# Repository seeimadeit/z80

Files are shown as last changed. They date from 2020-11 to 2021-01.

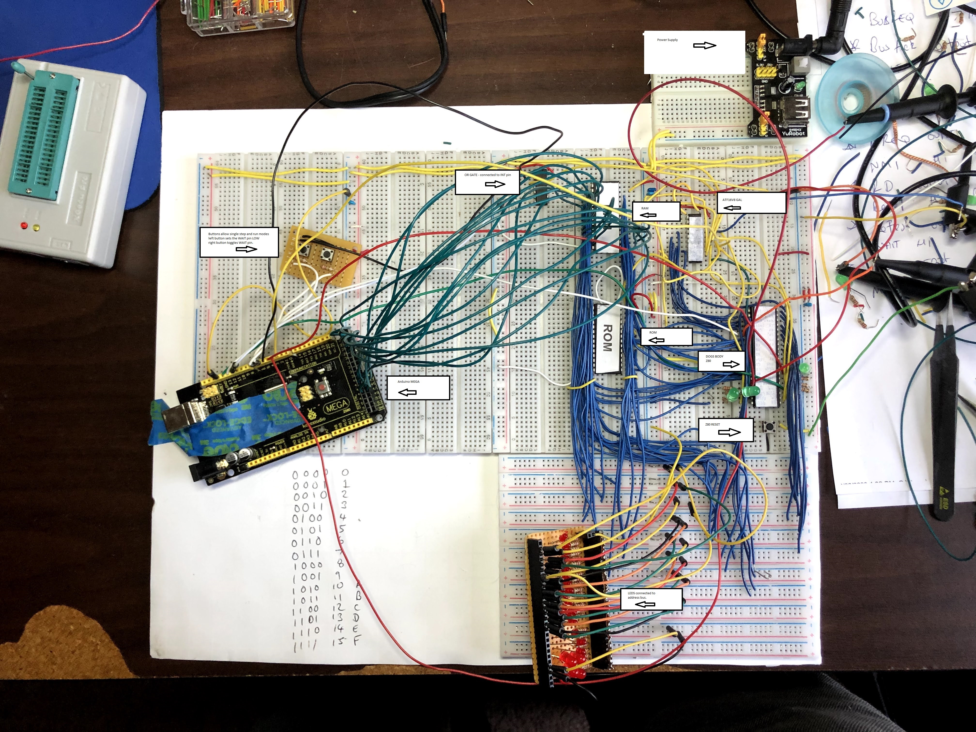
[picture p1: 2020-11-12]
initial/pictures/initialdesign.jpg

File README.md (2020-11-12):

# z80
my z80 based computer

my tools
---- arduino mega ----
during project startup im using it to provide a clock source and a serial port configured as a device on the z80 so I use it for basic keyboard IO.
the project will remove this at some point in the future..
https://www.arduino.cc/en/software

----- chip programmer ---
tl866II plus
www.xgecu.com
rom - at28c64b
gal - ATF16LV8CZ - provides logic for rom and ram selection.
source code for GAL and ROM available on github

------ svn tool ---
oxygenxml

----- gal programming language ----
wincupl

https://www.microchip.com/design-centers/fpgas-and-plds/splds-cplds/pld-design-resources

-------- rom code -----
vasm
http://sun.hasenbraten.de/vasm/
initial rom code written with vasm. I'll be moving to z88dk in the future.

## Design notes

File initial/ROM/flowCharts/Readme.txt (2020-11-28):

free for non-commerial use

ClickCharts Diagram & Flowchart Software
https://www.nchsoftware.com/chart/index.html

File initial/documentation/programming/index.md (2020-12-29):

# Index

[some ideas](ideas.md)

[library](library.md)
[processinfo](processinfo.md)
[commandline](commandline.md)

A

B

C  

[createprocess](createprocess.md)  

D  

filesystem - primitive functions, probably going to change  

[directoryopen](directory.md) 

[directorynextfile](directory.md) 

E

F

G  

[getcommandparams](getcommandparams.md)

[getfilename](directory.md) 

[getmalloctable](getmalloctable.md)

[getprocid](getprocid.md)

[getprocessbyid](getprocessbyid.md)

H  

[hextobyte.md](hextobyte.md) 

I

J

K

L  

[loadfile](loadfile.md)  

M  

[memset](memset.md)  

N

[nextprocessinfo](startprocessinfo.md)

O

P

[print](print.md) 

[println](print.md)

[printhex](printhex.md)  

[printhexL](printhex.md)  

[putc](putc.md) 

[processinfo](processinfo.md)

Q

R

S  
[strcpy](strcpy.md)

[strncpy](strncpy.md)  

[strlen](strlen.md)

[startprocessinfo](startprocessinfo.md)

[setresetpage](setresetpage.md) - memory alloc table management

T  

[touppercase](touppercase.md)

U

V

W

X

Y

Z

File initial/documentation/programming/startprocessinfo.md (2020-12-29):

# startprocessinfo

;#== startprocessinfo ==#  
;# reset the process info list pointer  
;# no inputs, no outputs  

;#== nextprocessinfo ===#  
;# return in hl the next processinfo entry  
;# also updates currentprocessinfo  
;# if carry flag set, we have reach the end of the process table

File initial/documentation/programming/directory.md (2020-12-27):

[index.md](index.md)
# directory utils

**directoryopen** - no inputs , outputs  
    opens the directory  
    
**directorynextfile** - no inpts , no outputs  
    advances to the next file  
    
**getfilename**  
    return the current filename in the HL register pair  
	;# === getfilename of currently open file ===#  
	;# ld hl,storagelocation - for the filename  
	;# call getfilename  

```
.include "Routines.inc"
.include "libs.inc"

	ld hl,dirmsg
	call println
	call directoryopen
currentfile:
	ld hl,thisfilename
	call getfilename
	call println

	ld a,(hl)
	cp 0
	jp z,_exit$1

	call directorynextfile
	jp currentfile

_exit$1:
	ret

thisfilename: .space 15
dirmsg: .string "\r\nDIRECTORY\r\n"

ENDADDRESS:
```

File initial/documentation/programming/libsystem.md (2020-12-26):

[index.md](index.md)
# system library

the system library is normally loaded automatically through Routines.inc and libs.inc

```
.include "Routines.inc"
.include "libs.inc"

```

.equ PRINT,		1  

.equ PRINTLN,	9  

.equ PRINTHEX,	2  

.equ LOADFILE,	3  

.equ MEMSET,	4  

.equ STRLEN,	5  

.equ PUTC,		6  

.equ TOUPPERCASE,7  

.equ HEXTOBYTE,	8  
[hextobyte.md](hextobyte.md)

.equ STRNCPY,10  

.equ CREATEPROCESS,16  

.equ GETCOMMANDPARAMS,17  

filesystem - primitive functions, probably going to change  

.equ DIRECTORYOPEN,13 

.equ DIRECTORYNEXTFILE,14  

.equ GETFILENAME,15

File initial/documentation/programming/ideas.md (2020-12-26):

# Ideas

1. malloc implementation  

            a program will be able list memory allocated
1. copy and paste ability
1. multitasking - can't start until the hardware is fully developed, ie. it needs a timer
1. move keyboard handler into kernel

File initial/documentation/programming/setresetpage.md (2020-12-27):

[index.md](index.md)
# setresetpage

;# ======= setresetpage - memory alloc table management ===#  
setresetpage:  
;# ld a, page  
;# ld b, setorreset , 0 = reset, 1 = set  

```

.include "Routines.inc"
.include "libs.inc"

	ld hl,params
	call getcommandparams
	call touppercase
		call strlen
		ld a,b
	
		cp 3
		jp nz, error

		ld ix,params ;# get the 1st and 2nd characters into the lobyte
		ld a,(ix)
		sub '0'
	
		ld b,a ;# flag 0 = reset, 1 = set
		ld h,(ix+1)
		ld l,(ix+2)
		call hextobyte

		call setresetpage
		ld a,0
		ret
error:
	ld hl,errormsg
	call println
	ld a,0
	ret

  errormsg: .string "syntax: setmat aXX where a = set or reset (1 or 0), XX page (see m*)"
  
	params: .space 50
ENDADDRESS:
```

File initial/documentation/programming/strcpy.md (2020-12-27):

[index.md](index.md)
# strcpy

# === strcpy == #  
	;# copy from source into destination string is zero terminated, no validation is done  
	;# ld hl,source  
	;# ld de,destination  
	;# call strcpy

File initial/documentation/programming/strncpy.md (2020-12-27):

[index.md](index.md)
# strncpy

	#=== strncpy ==#
	;# copy from source into destination size bytes. no validation is done.
	;# ld hl, source
	;# ld de, destination
	;# ld bc, size

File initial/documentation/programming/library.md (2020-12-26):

[index.md](index.md)

# Creating a Library
-- please use a markdown document viewer to read this file --  

A library is a binary executable file, it can load at any location in memory as specified by the library. In the future library's will be code relocatable.
The LIB will not contain a main() function, and will not execute code when loaded. Instead the code execution will happen only at the request of a calling
application. Its purpose is to store reusable and sharable code. It can be called by multiple applications. As the code is sharable care should be taken to
ensure the code doesn't stamp over other applications variables.

## screen.s

```
001 .set __LIB__,1
002 .set __ORG__,0x3000
003
004 .include "Routines.inc"
005 .include "libs.inc"
006 .include "screen.inc"
007 test:
008     ld hl,msg
009     call print
010     ret
011     msg: .string "hello I'm in screen.lib"
012
013 ;# === libaddress == #
014 ;#ld a,x - where x = instruction id
015 ;#	id = 2, test
016 libaddress:
017     cp 0
018     jp nz,_2$:
019     jp initialize
020 _2$:
021     cp TEST
022     jp nz, _end$
023     ld hl,test
024     ret
025 _end$:
026 #----- not defined ---
027     ld hl,0
028     ret
```

001 : Defining the ```__LIB__``` symbol will output a library binary

002 : optionally set the library load address, if not specified the default is 0xF000  

004 - 006 : include any required files etc  

007 - 011 : your program instructions  

The purpose of the libaddress routine is to return the address of a library function. If the function number is 0 (i.e. ld a,0) call the library initalize routine.

016 :  libaddress: is required, its the extry point for function runtime linking  

017 - 018 test for the library initialize routine.  

019 : run the initialize routine (see below)  

020 - 023 : check for the "test" function and return the address of the library function  

025 - 028 : default case, where no match is found return a null address  

## FAQ
 
where does the value TEST come from?  It's defined in the library include file. In the example it's defined in **screen.inc**  
```
...
.equ TEST,2
..
```

## initialize:
This routine is auto generated from **libs.inc** file. It will allow your library access to the main OS functions. For example the print, println and printhex routines are linked to your program code from the initalize routine.

# Load and Use a Library

To use the library we first need to load it into memory. After the binary has been loaded, the base address of the
library is returned in the HL register pair. You will need to save that address so you can call the base address to query
the library for the address of the functions it contains (phew). Librarys need to be initialized before using the library.
You can do that by calling the base address and pass 0 into the A register. To get the address of a library function
call the baseaddress with a function number of the routine in the A register. The library will have an include file that will define the
id's of the functions. Save the returned address in the HL register pair. It's important you save the address information into the
correct byte structure as defined in the example in lines 017 - 020. The predefined byte value is an assembler
instruction for jump. When you call the function it will jump to the address provided by the library.

```
000 .include "screen.inc"
...
001 loadlibrary:
002     ld hl,loadfilename
003     ld de,0
004     call loadfile
005     cp a,0 ;# if A = 0 then the file loaded successfully
006     jp nz,_1$:
007     ld (_screenbase),hl
008     ld a,0 ;# initialize the dll
009     call fnScreenGetAddress
010     ld a,TEST
011     call fnScreenGetAddress
012     ld (_testadr),hl
013     call fnTest
014 _1$: ret
015
016 loadfilename: .string "screen.lib"	
017 fnScreenGetAddress: .byte 0xc3
018        _screenbase: .2byte 0
019 fnTest:       .byte 0xc3
020     _testadr: .2byte 0
```

000 : load the library include file, this will contain the function id values and probably other information to use the library  

001 : define a subroutine called loadlibrary  

002 - 004 : call the loadfile function passing in the filename (see loadfile for details)  

005 : validate the load call worked  

006 : if it failed we will just exit  

007 : the load returns the base address into the hl register pair, save that address for later use  

008 - 009 : call the library initialize routine  

010 - 012 : ask for the address of TEST function and store the address for later use  

013 : call the library test function  

014 : exit the subroutine  

016 : define the library filename  

017 - 018 : 0xc3 is the byte code for the z80 jump (JP) instruction, the address is stored in the 2 bytes after this bytecode. This allows our code to call the library function.  

019 - 020 : define our jump instruction and reserve 2 bytes for the library address

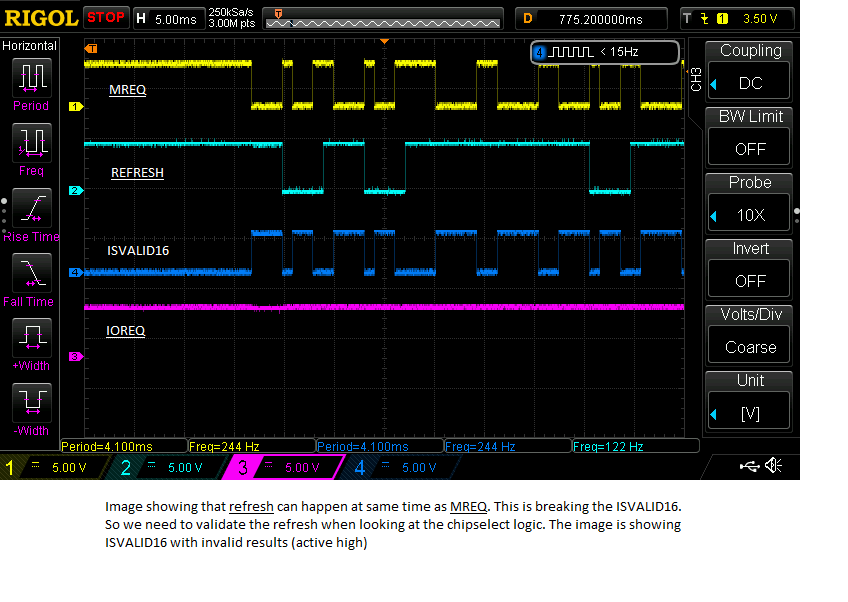
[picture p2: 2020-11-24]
initial/wincupl/MemChipSelect/ScopeImage_Refresh.png

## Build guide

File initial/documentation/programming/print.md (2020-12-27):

# Title

	# === PRINTLN == #
	ld hl, string to print
	println: ;// same as print but appends CRLF

	# === PRINT === #
	ld hl, string to print
	print: ;// expecting a zero terminated string

```
	ld hl,msg
	call println
	ret
	
	msg: .string "hello"
```

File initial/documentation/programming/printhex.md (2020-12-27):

[index.md](index.md)
# printhex , printhexL

;l# === PRINTHEX === #  
		;Display 8-bit number in hex.  
		; 	ld a,0xaa  
	;       call printhex  

;#=== printhexL ===#  
;# ld hl,passwords  
;# call printhexL

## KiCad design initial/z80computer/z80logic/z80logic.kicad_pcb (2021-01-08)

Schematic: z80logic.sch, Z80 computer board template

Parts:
ANDWAIT1: SN74HC21N; DIP-14_W7.62mm_Socket
C1, C9: 0.1uF; C_Axial_L5.1mm_D3.1mm_P7.50mm_Horizontal
C2, C4, C12, C13: perf_9x4symbol; perf_9x4
C3: 1.0uF; C_Axial_L3.8mm_D2.6mm_P7.50mm_Horizontal
C5, C14, C15, C16, C17, C18, C19, C20: perf_13x4symbol; perf_13x4
C6, C10, C11: perf_12x4symbol; perf_12x4
C7, C8: perf_36x4symbol; perf_36x4
CLOCK1: PIC18F24Q10-xSP; DIP-28_W7.62mm
IOPORT1: GAL16V8; DIP-20_W7.62mm_Socket
J1: pin header 855-M20-9953645; PinHeader_2x36_P2.54mm_Horizontal
J2: Conn_02x03_Top_Bottom; PinHeader_2x03_P2.54mm_Horizontal
J3: Conn_02x03_Odd_Even; PinSocket_2x03_P2.54mm_Vertical
MEMCHIPSELECT1: MEMCHIPSELECT; DIP-20_W7.62mm_Socket
OR1: SN74LS32N; DIP-14_W7.62mm_Socket
R1, R2: 1K; R_Axial_DIN0207_L6.3mm_D2.5mm_P10.16mm_Horizontal
SW1: SW_SPST; SW_PUSH_6mm_H8mm

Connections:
/17: C7.33, C7.34, C7.35, C7.36, J1.17
/18: C8.33, C8.34, C8.35, C8.36, J1.18
/27: C7.53, C7.54, C7.55, C7.56, J1.27
/28: C8.53, C8.54, C8.55, C8.56, J1.28
/42: C8.81, C8.82, C8.83, C8.84, J1.42
/43: C7.85, C7.86, C7.87, C7.88, J1.43
/44: C8.85, C8.86, C8.87, C8.88, J1.44
/48: C8.93, C8.94, C8.95, C8.96, J1.48
/49: C7.97, C7.98, C7.99, C7.100, J1.49
/50: C8.97, C8.98, C8.99, C8.100, J1.50
/54: C8.105, C8.106, C8.107, C8.108, J1.54
/55: C7.109, C7.110, C7.111, C7.112, J1.55
/56: C8.109, C8.110, C8.111, C8.112, J1.56
/60: C8.117, C8.118, C8.119, C8.120, J1.60
/61: C7.121, C7.122, C7.123, C7.124, J1.61
/62: C8.121, C8.122, C8.123, C8.124, J1.62
/63: C7.125, C7.126, C7.127, C7.128, J1.63
/64: C8.125, C8.126, C8.127, C8.128, J1.64
/65: C7.129, C7.130, C7.131, C7.132, J1.65
/66: C8.129, C8.130, C8.131, C8.132, J1.66
/67: C7.133, C7.134, C7.135, C7.136, J1.67
/68: C8.133, C8.134, C8.135, C8.136, J1.68
/69: C7.137, C7.138, C7.139, C7.140, J1.69
/70: C8.137, C8.138, C8.139, C8.140, J1.70
/71: C7.141, C7.142, C7.143, C7.144, J1.71
/72: C8.141, C8.142, C8.143, C8.144, J1.72
/A0: C7.1, C7.2, C7.3, C7.4, C12.1, C12.2, C12.3, C12.4, IOPORT1.1, J1.1
/A1: C8.1, C8.2, C8.3, C8.4, C12.5, C12.6, C12.7, C12.8, IOPORT1.2, J1.2
/A1A: ANDWAIT1.1, C10.1, C10.2, C10.3, C10.4
/A1B: ANDWAIT1.2, C10.5, C10.6, C10.7, C10.8
/A1C: ANDWAIT1.4, C10.9, C10.10, C10.11, C10.12
/A1CS: C4.25, C4.26, C4.27, C4.28, C7.105, C7.106, C7.107, C7.108, J1.53, MEMCHIPSELECT1.13
/A1D: ANDWAIT1.5, C10.13, C10.14, C10.15, C10.16
/A1OE: C8.101, C8.102, C8.103, C8.104, J1.52
/A1WE: C7.101, C7.102, C7.103, C7.104, J1.51
/A1Y: ANDWAIT1.6, C10.17, C10.18, C10.19, C10.20
/A2: C7.5, C7.6, C7.7, C7.8, C12.9, C12.10, C12.11, C12.12, IOPORT1.3, J1.3
/A2A: ANDWAIT1.9, C10.21, C10.22, C10.23, C10.24
/A2B: ANDWAIT1.10, C10.25, C10.26, C10.27, C10.28
/A2C: ANDWAIT1.12, C10.29, C10.30, C10.31, C10.32
/A2CS: C4.21, C4.22, C4.23, C4.24, C7.117, C7.118, C7.119, C7.120, J1.59, MEMCHIPSELECT1.14
/A2D: ANDWAIT1.13, C10.33, C10.34, C10.35, C10.36
/A2OE: C8.113, C8.114, C8.115, C8.116, J1.58
/A2WE: C7.113, C7.114, C7.115, C7.116, J1.57
/A2Y: ANDWAIT1.8, C10.37, C10.38, C10.39, C10.40
/A3: C8.5, C8.6, C8.7, C8.8, C12.13, C12.14, C12.15, C12.16, IOPORT1.4, J1.4
/A4: C7.9, C7.10, C7.11, C7.12, J1.5
/A5: C8.9, C8.10, C8.11, C8.12, J1.6
/A6: C7.13, C7.14, C7.15, C7.16, J1.7
/A7: C8.13, C8.14, C8.15, C8.16, J1.8
/A8: C7.17, C7.18, C7.19, C7.20, J1.9
/A9: C8.17, C8.18, C8.19, C8.20, J1.10
/A10: C7.21, C7.22, C7.23, C7.24, J1.11
/A11: C2.17, C2.18, C2.19, C2.20, C8.21, C8.22, C8.23, C8.24, J1.12, MEMCHIPSELECT1.5
/A12: C2.21, C2.22, C2.23, C2.24, C7.25, C7.26, C7.27, C7.28, J1.13, MEMCHIPSELECT1.6
/A13: C2.25, C2.26, C2.27, C2.28, C8.25, C8.26, C8.27, C8.28, J1.14, MEMCHIPSELECT1.7
/A14: C2.29, C2.30, C2.31, C2.32, C7.29, C7.30, C7.31, C7.32, J1.15, MEMCHIPSELECT1.8
/A15: C2.33, C2.34, C2.35, C2.36, C8.29, C8.30, C8.31, C8.32, J1.16, MEMCHIPSELECT1.9
/BUSACK: C7.57, C7.58, C7.59, C7.60, J1.29
/BUSRQ: C8.57, C8.58, C8.59, C8.60, J1.30
/CLK: C5.33, C5.34, C5.35, C5.36, C7.81, C7.82, C7.83, C7.84, CLOCK1.10, J1.41
/D0: C7.37, C7.38, C7.39, C7.40, J1.19
/D1: C8.37, C8.38, C8.39, C8.40, J1.20
/D2: C7.41, C7.42, C7.43, C7.44, J1.21
/D3: C8.41, C8.42, C8.43, C8.44, J1.22
/D4: C7.45, C7.46, C7.47, C7.48, J1.23
/D5: C8.45, C8.46, C8.47, C8.48, J1.24
/D6: C7.49, C7.50, C7.51, C7.52, J1.25
/D7: C8.49, C8.50, C8.51, C8.52, J1.26
/GND: ANDWAIT1.7, C1.2, C3.2, C9.2, CLOCK1.19, IOPORT1.10, J2.6, J3.5, MEMCHIPSELECT1.10, OR1.7, SW1.2
/HALT: C7.69, C7.70, C7.71, C7.72, J1.35
/INT: C7.77, C7.78, C7.79, C7.80, J1.39
/IORQ: C4.9, C4.10, C4.11, C4.12, C7.61, C7.62, C7.63, C7.64, C12.17, C12.18, C12.19, C12.20, IOPORT1.5, J1.31, MEMCHIPSELECT1.17
/M1: C8.73, C8.74, C8.75, C8.76, C12.29, C12.30, C12.31, C12.32, IOPORT1.8, J1.38
/MREQ: C4.33, C4.34, C4.35, C4.36, C8.61, C8.62, C8.63, C8.64, J1.32, MEMCHIPSELECT1.11
/NMI: C8.77, C8.78, C8.79, C8.80, J1.40
/O1A: C11.1, C11.2, C11.3, C11.4, OR1.1
/O1B: C11.5, C11.6, C11.7, C11.8, OR1.2
/O1Y: C11.9, C11.10, C11.11, C11.12, OR1.3
/O2A: C11.13, C11.14, C11.15, C11.16, OR1.4
/O2B: C11.17, C11.18, C11.19, C11.20, OR1.5
/O2Y: C11.21, C11.22, C11.23, C11.24, OR1.6
/O3A: C11.25, C11.26, C11.27, C11.28, OR1.9
/O3B: C11.29, C11.30, C11.31, C11.32, OR1.10
/O3Y: C11.33, C11.34, C11.35, C11.36, OR1.8
/O4A: C11.37, C11.38, C11.39, C11.40, OR1.12
/O4B: C11.41, C11.42, C11.43, C11.44, OR1.13
/O4Y: C11.45, C11.46, C11.47, C11.48, OR1.11
/OCS: C4.29, C4.30, C4.31, C4.32, C7.93, C7.94, C7.95, C7.96, J1.47, MEMCHIPSELECT1.12
/OOE: C8.89, C8.90, C8.91, C8.92, J1.46
/OWE: C7.89, C7.90, C7.91, C7.92, J1.45
/POWER2: J2.2, J3.1
/POWER3: J2.3, J3.4
/PUSH: C6.41, C6.42, C6.43, C6.44, CLOCK1.16, R2.2
/RD: C8.65, C8.66, C8.67, C8.68, J1.34
/RESET: J2.1, J3.2
/RFSH: C4.17, C4.18, C4.19, C4.20, C7.73, C7.74, C7.75, C7.76, C12.21, C12.22, C12.23, C12.24, IOPORT1.6, J1.37, MEMCHIPSELECT1.15
/VCC3: J2.4, J3.3
/VCC5: ANDWAIT1.14, C1.1, C3.1, C5.1, C5.2, C5.3, C5.4, C9.1, C14.4, C14.8, C14.12, C14.16, C14.20, C14.24, C14.28, C14.32, C14.36, C14.40, C14.44, C14.48, C14.52, C17.49, C17.50, C17.51, C17.52, CLOCK1.1, CLOCK1.8, CLOCK1.20, IOPORT1.20, J2.5, J3.6, MEMCHIPSELECT1.20, OR1.14, R1.2
/WAIT: C8.69, C8.70, C8.71, C8.72, J1.36
/WR: C7.65, C7.66, C7.67, C7.68, J1.33
unnamed: C2.1, C2.2, C2.3, C2.4, MEMCHIPSELECT1.1
unnamed: C2.5, C2.6, C2.7, C2.8, MEMCHIPSELECT1.2
unnamed: C2.9, C2.10, C2.11, C2.12, MEMCHIPSELECT1.3
unnamed: C2.13, C2.14, C2.15, C2.16, MEMCHIPSELECT1.4
unnamed: C4.1, C4.2, C4.3, C4.4, MEMCHIPSELECT1.19
unnamed: C4.5, C4.6, C4.7, C4.8, MEMCHIPSELECT1.18
unnamed: C4.13, C4.14, C4.15, C4.16, MEMCHIPSELECT1.16
unnamed: C5.5, C5.6, C5.7, C5.8, CLOCK1.2
unnamed: C5.9, C5.10, C5.11, C5.12, CLOCK1.3
unnamed: C5.13, C5.14, C5.15, C5.16, CLOCK1.4
unnamed: C5.17, C5.18, C5.19, C5.20, CLOCK1.5
unnamed: C5.21, C5.22, C5.23, C5.24, CLOCK1.6
unnamed: C5.25, C5.26, C5.27, C5.28, CLOCK1.7
unnamed: C5.29, C5.30, C5.31, C5.32, CLOCK1.9
unnamed: C5.37, C5.38, C5.39, C5.40, CLOCK1.11
unnamed: C5.41, C5.42, C5.43, C5.44, CLOCK1.12
unnamed: C5.45, C5.46, C5.47, C5.48, CLOCK1.13
unnamed: C5.49, C5.50, C5.51, C5.52, CLOCK1.14
unnamed: C6.1, C6.2, C6.3, C6.4, CLOCK1.28
unnamed: C6.5, C6.6, C6.7, C6.8, CLOCK1.27
unnamed: C6.9, C6.10, C6.11, C6.12, CLOCK1.26
unnamed: C6.13, C6.14, C6.15, C6.16, CLOCK1.25
unnamed: C6.17, C6.18, C6.19, C6.20, CLOCK1.24
unnamed: C6.21, C6.22, C6.23, C6.24, CLOCK1.23
unnamed: C6.25, C6.26, C6.27, C6.28, CLOCK1.22
unnamed: C6.29, C6.30, C6.31, C6.32, CLOCK1.21
unnamed: C6.33, C6.34, C6.35, C6.36, CLOCK1.18
unnamed: C6.37, C6.38, C6.39, C6.40, CLOCK1.17
unnamed: C6.45, C6.46, C6.47, C6.48, CLOCK1.15
unnamed: C10.41, C10.42, C10.43, C10.44
unnamed: C10.45, C10.46, C10.47, C10.48
unnamed: C12.25, C12.26, C12.27, C12.28, IOPORT1.7
unnamed: C12.33, C12.34, C12.35, C12.36, IOPORT1.9
unnamed: C13.1, C13.2, C13.3, C13.4, IOPORT1.19
unnamed: C13.5, C13.6, C13.7, C13.8, IOPORT1.18
unnamed: C13.9, C13.10, C13.11, C13.12, IOPORT1.17
unnamed: C13.13, C13.14, C13.15, C13.16, IOPORT1.16
unnamed: C13.17, C13.18, C13.19, C13.20, IOPORT1.15
unnamed: C13.21, C13.22, C13.23, C13.24, IOPORT1.14
unnamed: C13.25, C13.26, C13.27, C13.28, IOPORT1.13
unnamed: C13.29, C13.30, C13.31, C13.32, IOPORT1.12
unnamed: C13.33, C13.34, C13.35, C13.36, IOPORT1.11
unnamed: R1.1, R2.1, SW1.1

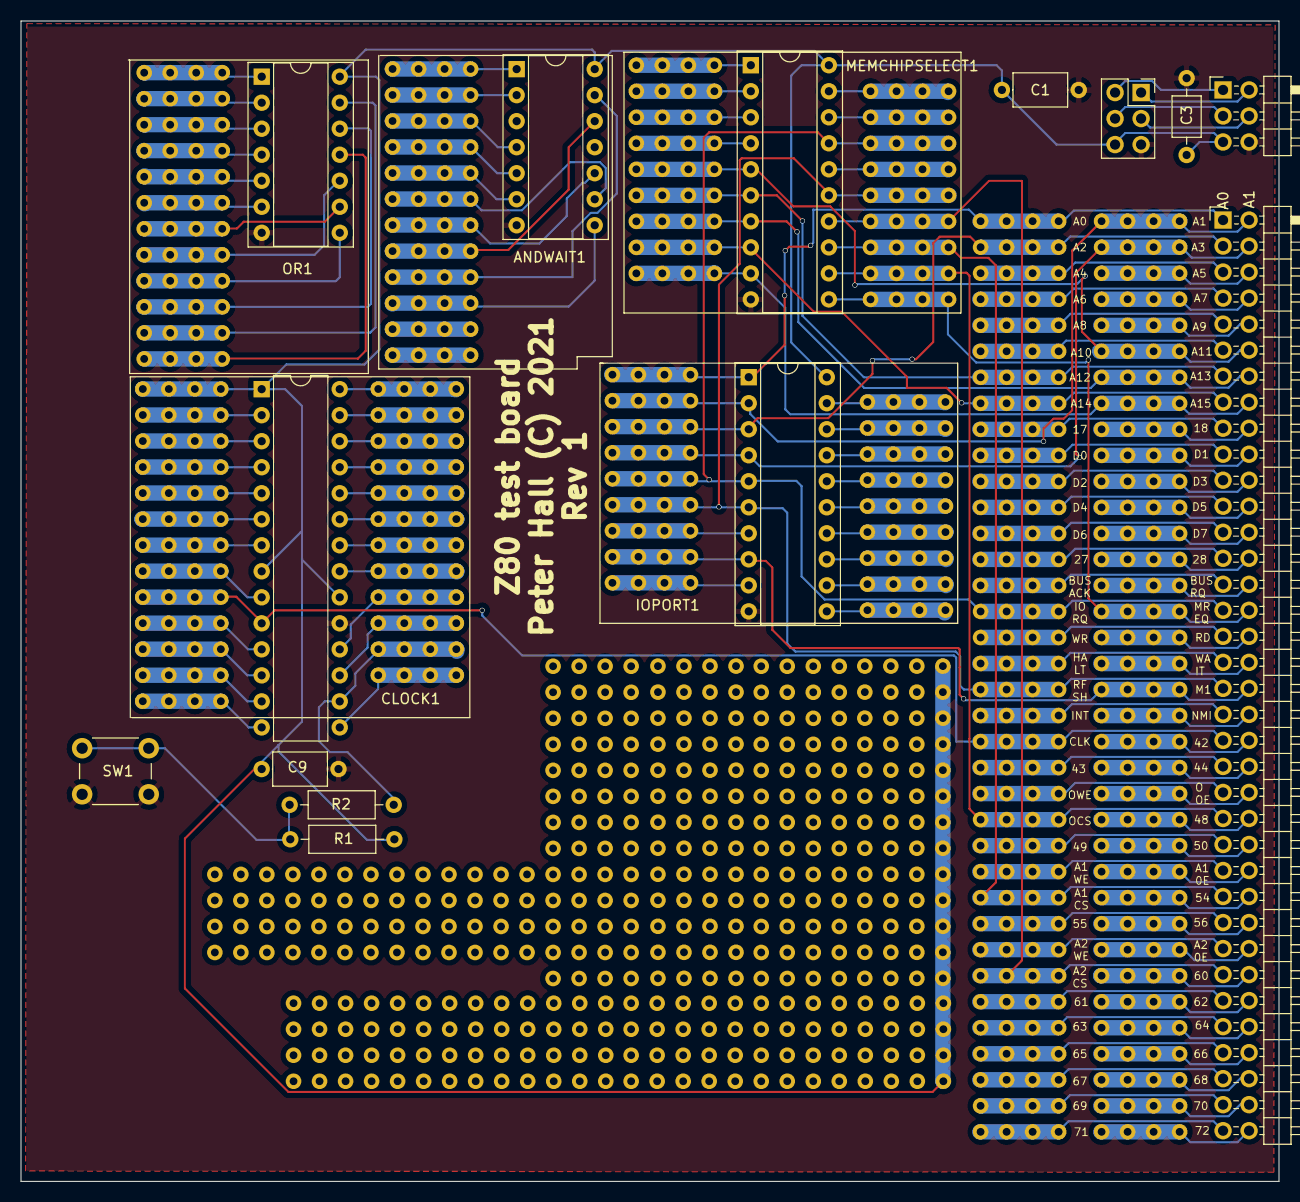
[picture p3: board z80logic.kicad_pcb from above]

Board: 2 copper layers, 122.8 x 113.3 mm, 31 parts (0 on the bottom side), 144 nets.

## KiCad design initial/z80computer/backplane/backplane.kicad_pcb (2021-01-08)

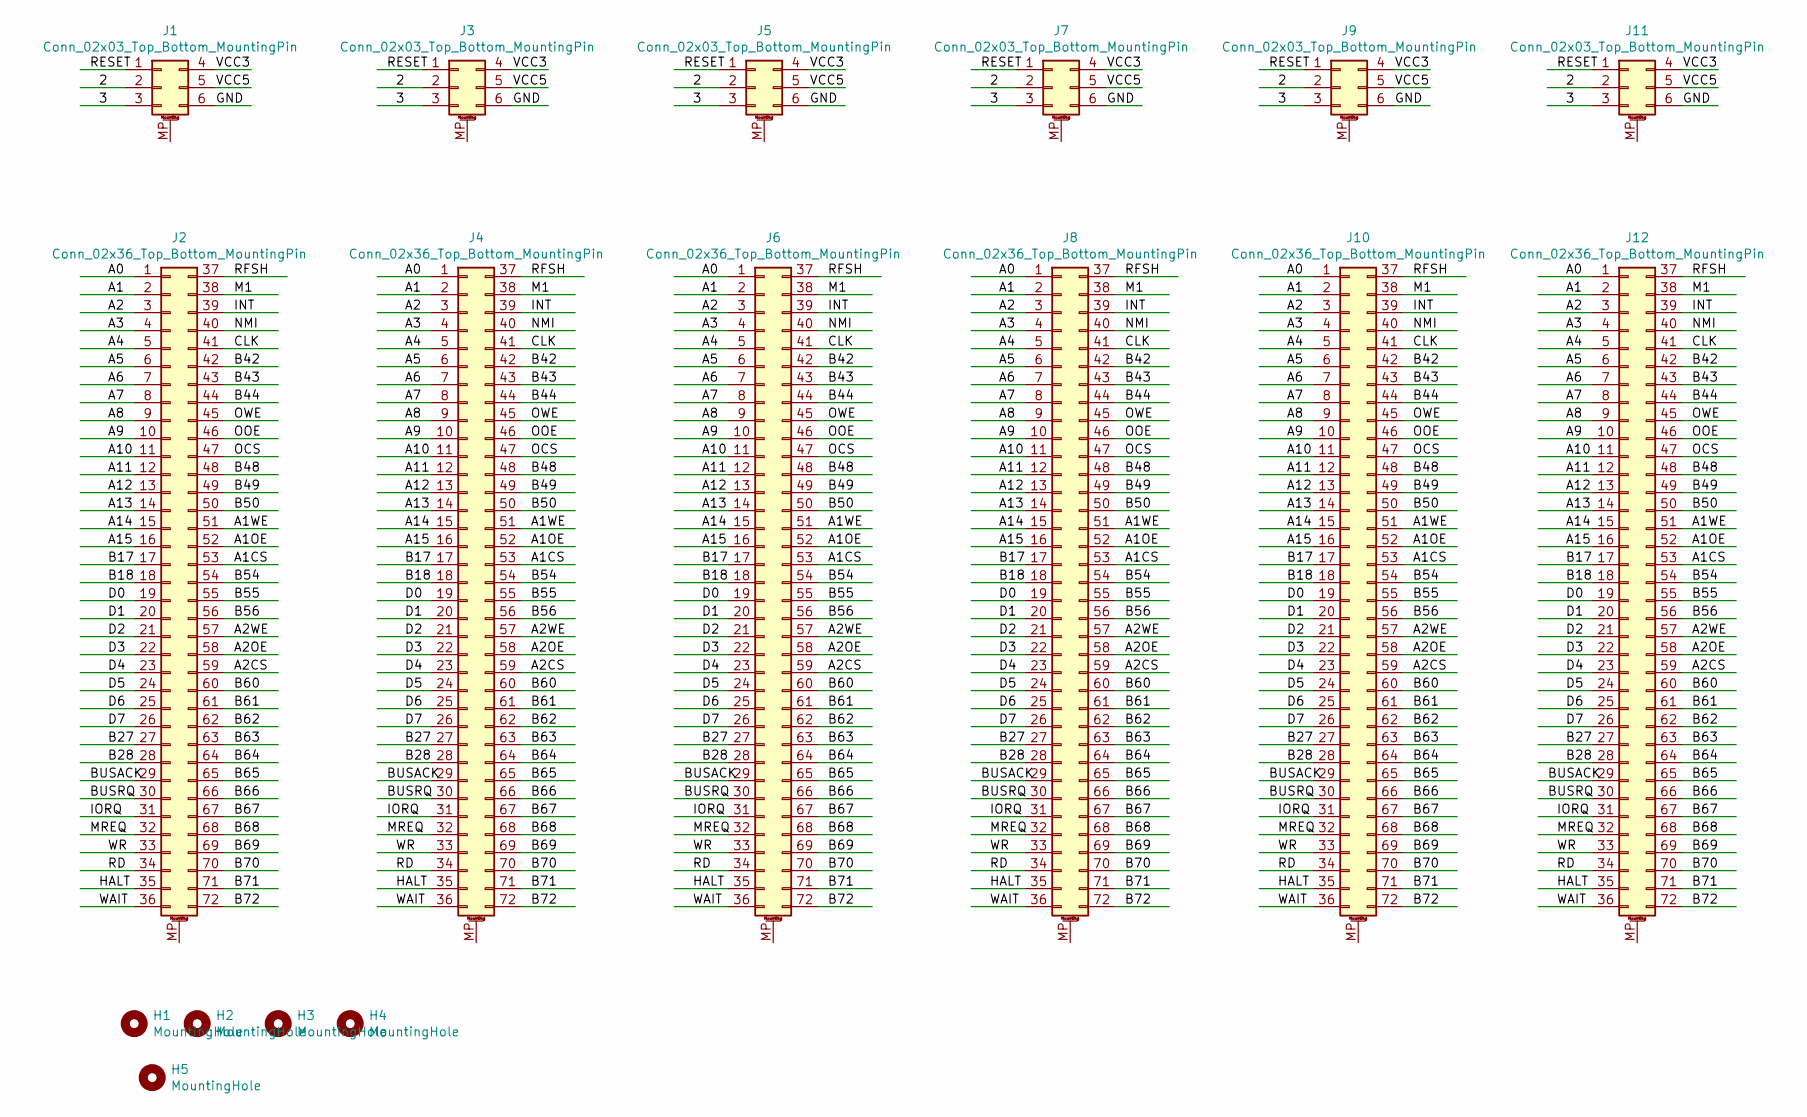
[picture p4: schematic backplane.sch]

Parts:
H1, H2, H3, H4: MountingHole; MountingHole_3mm_Pad_TopBottom
H5: MountingHole; MountingHole_2.1mm
J1, J3, J5, J7, J9, J11: Conn_02x03_Top_Bottom_MountingPin; PinSocket_2x03_P2.54mm_Vertical
J2, J4, J6, J8, J10, J12: Conn_02x36_Top_Bottom_MountingPin; PinSocket_2x36_P2.54mm_Vertical

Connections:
/2: J1.2, J3.2, J5.2, J7.2, J9.2, J11.2
/3: J1.3, J3.3, J5.3, J7.3, J9.3, J11.3
/A0: J2.1, J4.1, J6.1, J8.1, J10.1, J12.1
/A1: J2.2, J4.2, J6.2, J8.2, J10.2, J12.2
/A1CS: J2.53, J4.53, J6.53, J8.53, J10.53, J12.53
/A1OE: J2.52, J4.52, J6.52, J8.52, J10.52, J12.52
/A1WE: J2.51, J4.51, J6.51, J8.51, J10.51, J12.51
/A2: J2.3, J4.3, J6.3, J8.3, J10.3, J12.3
/A2CS: J2.59, J4.59, J6.59, J8.59, J10.59, J12.59
/A2OE: J2.58, J4.58, J6.58, J8.58, J10.58, J12.58
/A2WE: J2.57, J4.57, J6.57, J8.57, J10.57, J12.57
/A3: J2.4, J4.4, J6.4, J8.4, J10.4, J12.4
/A4: J2.5, J4.5, J6.5, J8.5, J10.5, J12.5
/A5: J2.6, J4.6, J6.6, J8.6, J10.6, J12.6
/A6: J2.7, J4.7, J6.7, J8.7, J10.7, J12.7
/A7: J2.8, J4.8, J6.8, J8.8, J10.8, J12.8
/A8: J2.9, J4.9, J6.9, J8.9, J10.9, J12.9
/A9: J2.10, J4.10, J6.10, J8.10, J10.10, J12.10
/A10: J2.11, J4.11, J6.11, J8.11, J10.11, J12.11
/A11: J2.12, J4.12, J6.12, J8.12, J10.12, J12.12
/A12: J2.13, J4.13, J6.13, J8.13, J10.13, J12.13
/A13: J2.14, J4.14, J6.14, J8.14, J10.14, J12.14
/A14: J2.15, J4.15, J6.15, J8.15, J10.15, J12.15
/A15: J2.16, J4.16, J6.16, J8.16, J10.16, J12.16
/B17: J2.17, J4.17, J6.17, J8.17, J10.17, J12.17
/B18: J2.18, J4.18, J6.18, J8.18, J10.18, J12.18
/B27: J2.27, J4.27, J6.27, J8.27, J10.27, J12.27
/B28: J2.28, J4.28, J6.28, J8.28, J10.28, J12.28
/B42: J2.42, J4.42, J6.42, J8.42, J10.42, J12.42
/B43: J2.43, J4.43, J6.43, J8.43, J10.43, J12.43
/B44: J2.44, J4.44, J6.44, J8.44, J10.44, J12.44
/B48: J2.48, J4.48, J6.48, J8.48, J10.48, J12.48
/B49: J2.49, J4.49, J6.49, J8.49, J10.49, J12.49
/B50: J2.50, J4.50, J6.50, J8.50, J10.50, J12.50
/B54: J2.54, J4.54, J6.54, J8.54, J10.54, J12.54
/B55: J2.55, J4.55, J6.55, J8.55, J10.55, J12.55
/B56: J2.56, J4.56, J6.56, J8.56, J10.56, J12.56
/B60: J2.60, J4.60, J6.60, J8.60, J10.60, J12.60
/B61: J2.61, J4.61, J6.61, J8.61, J10.61, J12.61
/B62: J2.62, J4.62, J6.62, J8.62, J10.62, J12.62
/B63: J2.63, J4.63, J6.63, J8.63, J10.63, J12.63
/B64: J2.64, J4.64, J6.64, J8.64, J10.64, J12.64
/B65: J2.65, J4.65, J6.65, J8.65, J10.65, J12.65
/B66: J2.66, J4.66, J6.66, J8.66, J10.66, J12.66
/B67: J2.67, J4.67, J6.67, J8.67, J10.67, J12.67
/B68: J2.68, J4.68, J6.68, J8.68, J10.68, J12.68
/B69: J2.69, J4.69, J6.69, J8.69, J10.69, J12.69
/B70: J2.70, J4.70, J6.70, J8.70, J10.70, J12.70
/B71: J2.71, J4.71, J6.71, J8.71, J10.71, J12.71
/B72: J2.72, J4.72, J6.72, J8.72, J10.72, J12.72
/BUSACK: J2.29, J4.29, J6.29, J8.29, J10.29, J12.29
/BUSRQ: J2.30, J4.30, J6.30, J8.30, J10.30, J12.30
/CLK: J2.41, J4.41, J6.41, J8.41, J10.41, J12.41
/D0: J2.19, J4.19, J6.19, J8.19, J10.19, J12.19
/D1: J2.20, J4.20, J6.20, J8.20, J10.20, J12.20
/D2: J2.21, J4.21, J6.21, J8.21, J10.21, J12.21
/D3: J2.22, J4.22, J6.22, J8.22, J10.22, J12.22
/D4: J2.23, J4.23, J6.23, J8.23, J10.23, J12.23
/D5: J2.24, J4.24, J6.24, J8.24, J10.24, J12.24
/D6: J2.25, J4.25, J6.25, J8.25, J10.25, J12.25
/D7: J2.26, J4.26, J6.26, J8.26, J10.26, J12.26
/GND: J1.6, J3.6, J5.6, J7.6, J9.6, J11.6
/HALT: J2.35, J4.35, J6.35, J8.35, J10.35, J12.35
/INT: J2.39, J4.39, J6.39, J8.39, J10.39, J12.39
/IORQ: J2.31, J4.31, J6.31, J8.31, J10.31, J12.31
/M1: J2.38, J4.38, J6.38, J8.38, J10.38, J12.38
/MREQ: J2.32, J4.32, J6.32, J8.32, J10.32, J12.32
/NMI: J2.40, J4.40, J6.40, J8.40, J10.40, J12.40
/OCS: J2.47, J4.47, J6.47, J8.47, J10.47, J12.47
/OOE: J2.46, J4.46, J6.46, J8.46, J10.46, J12.46
/OWE: J2.45, J4.45, J6.45, J8.45, J10.45, J12.45
/RD: J2.34, J4.34, J6.34, J8.34, J10.34, J12.34
/RESET: J1.1, J3.1, J5.1, J7.1, J9.1, J11.1
/RFSH: J2.37, J4.37, J6.37, J8.37, J10.37, J12.37
/VCC3: J1.4, J3.4, J5.4, J7.4, J9.4, J11.4
/VCC5: J1.5, J3.5, J5.5, J7.5, J9.5, J11.5
/WAIT: J2.36, J4.36, J6.36, J8.36, J10.36, J12.36
/WR: J2.33, J4.33, J6.33, J8.33, J10.33, J12.33

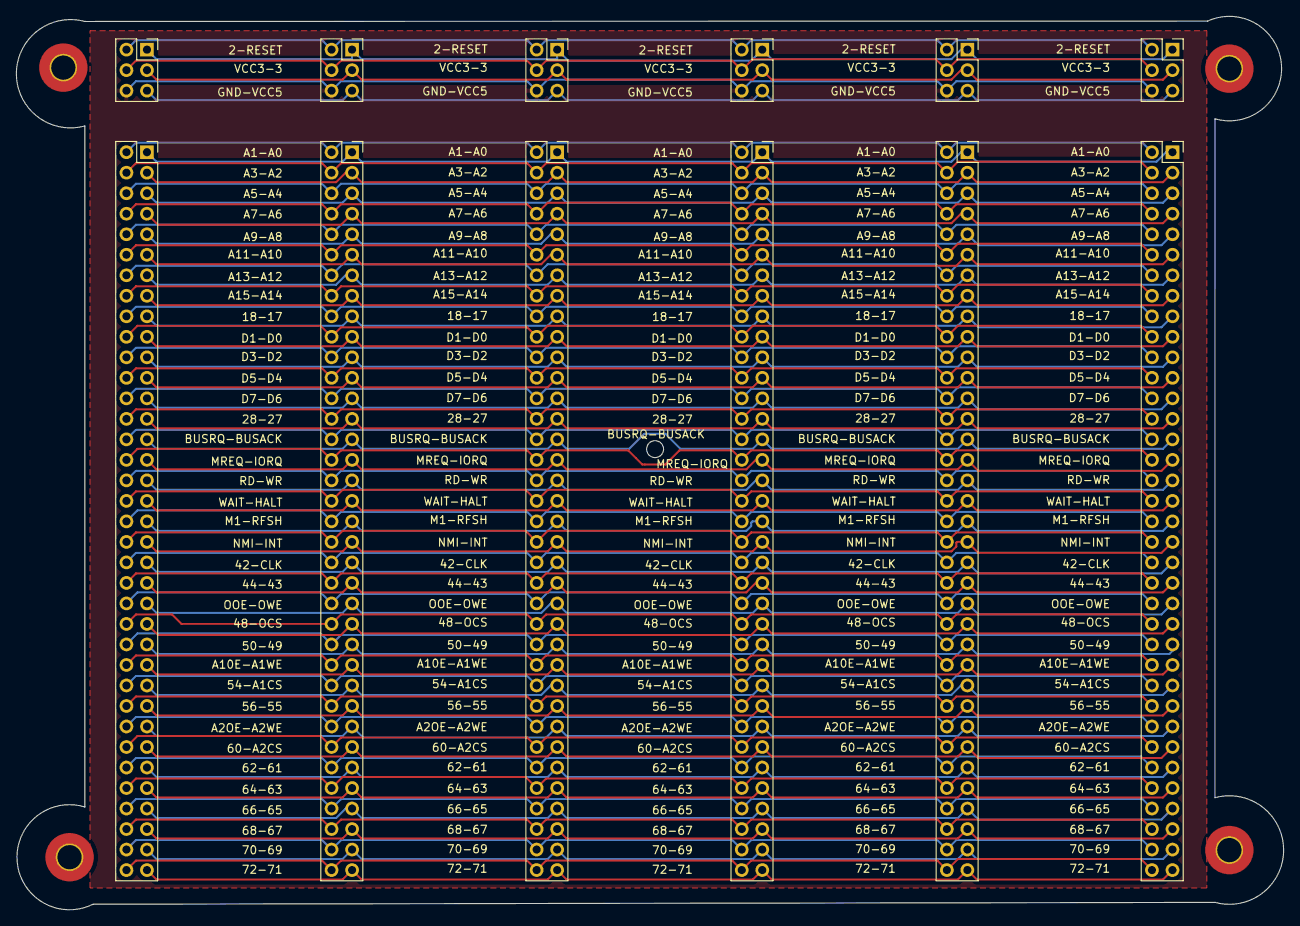
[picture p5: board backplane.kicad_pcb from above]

Board: 2 copper layers, 156.9 x 110.6 mm, 17 parts (0 on the bottom side), 78 nets.

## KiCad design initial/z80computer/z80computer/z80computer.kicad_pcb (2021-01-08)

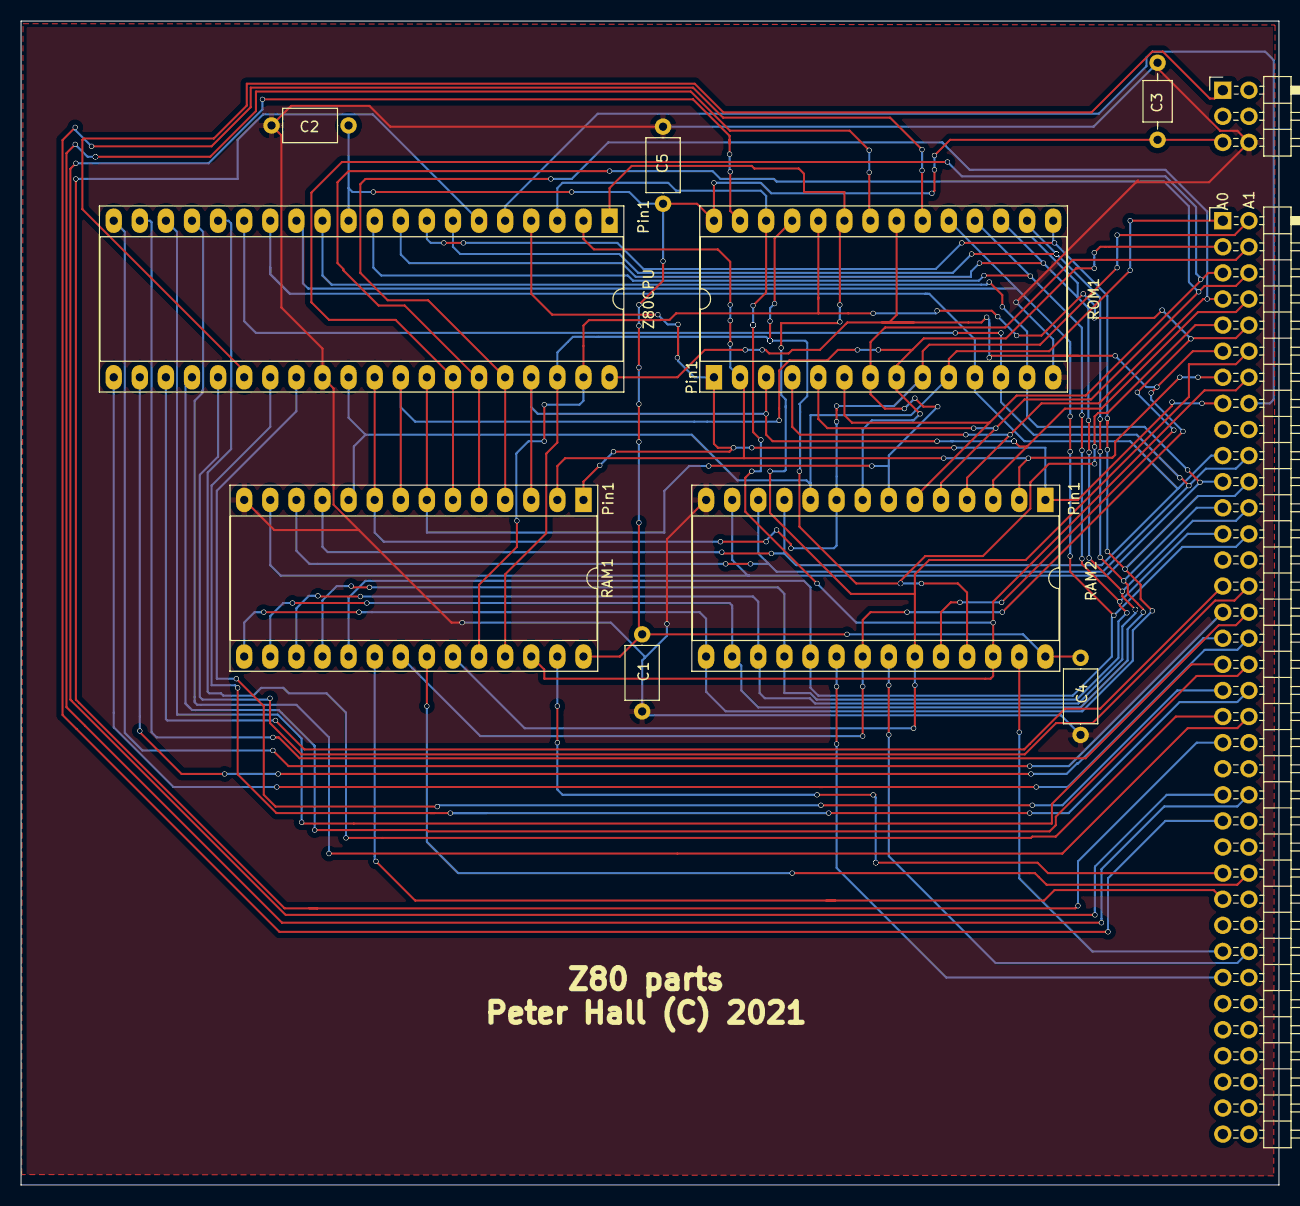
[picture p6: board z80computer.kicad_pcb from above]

Board: 2 copper layers, 122.4 x 113.3 mm, 11 parts (0 on the bottom side), 49 nets.

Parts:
C1, C2, C4, C5: 0.1uF; C_Axial_L5.1mm_D3.1mm_P7.50mm_Horizontal
C3: 1.0uF; C_Axial_L3.8mm_D2.6mm_P7.50mm_Horizontal
J1: pin header 855-M20-9953645; PinHeader_2x36_P2.54mm_Horizontal
J2: Conn_02x03_Top_Bottom; PinHeader_2x03_P2.54mm_Horizontal
RAM1, RAM2: AS6C62256; DIP-28_W15.24mm_Socket_LongPads
ROM1: AT28C64B; DIP-28_W15.24mm_Socket_LongPads
U4: Z80CPU; DIP-40_W15.24mm_Socket_LongPads

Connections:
/A0: J1.1, RAM1.10, RAM2.10, ROM1.10, U4.30
/A1: J1.2, RAM1.9, RAM2.9, ROM1.9, U4.31
/A1CS: J1.53, RAM1.20
/A1OE: J1.52, RAM1.22
/A1WE: J1.51, RAM1.27
/A2: J1.3, RAM1.8, RAM2.8, ROM1.8, U4.32
/A2CS: J1.59, RAM2.20
/A2OE: J1.58, RAM2.22
/A2WE: J1.57, RAM2.27
/A3: J1.4, RAM1.7, RAM2.7, ROM1.7, U4.33
/A4: J1.5, RAM1.6, RAM2.6, ROM1.6, U4.34
/A5: J1.6, RAM1.5, RAM2.5, ROM1.5, U4.35
/A6: J1.7, RAM1.4, RAM2.4, ROM1.4, U4.36
/A7: J1.8, RAM1.3, RAM2.3, ROM1.3, U4.37
/A8: J1.9, RAM1.25, RAM2.25, ROM1.25, U4.38
/A9: J1.10, RAM1.24, RAM2.24, ROM1.24, U4.39
/A10: J1.11, RAM1.21, RAM2.21, ROM1.21, U4.40
/A11: J1.12, RAM1.23, RAM2.23, ROM1.23, U4.1
/A12: J1.13, RAM1.2, RAM2.2, ROM1.2, U4.2
/A13: J1.14, RAM1.26, RAM2.26, ROM1.26, U4.3
/A14: J1.15, RAM1.1, RAM2.1, ROM1.1, U4.4
/A15: J1.16, U4.5
/BUSACK: J1.29, U4.23
/BUSRQ: J1.30, U4.25
/CLK: J1.41, U4.6
/D0: J1.19, RAM1.11, RAM2.11, ROM1.11, U4.14
/D1: J1.20, RAM1.12, RAM2.12, ROM1.12, U4.15
/D2: J1.21, RAM1.13, RAM2.13, ROM1.13, U4.12
/D3: J1.22, RAM1.15, RAM2.15, ROM1.15, U4.8
/D4: J1.23, RAM1.16, RAM2.16, ROM1.16, U4.7
/D5: J1.24, RAM1.17, RAM2.17, ROM1.17, U4.9
/D6: J1.25, RAM1.18, RAM2.18, ROM1.18, U4.10
/D7: J1.26, RAM1.19, RAM2.19, ROM1.19, U4.13
/GND: C1.2, C2.2, C3.2, C4.2, C5.2, J2.6, RAM1.14, RAM2.14, ROM1.14, U4.29
/HALT: J1.35, U4.18
/INT: J1.39, U4.16
/IORQ: J1.31, U4.20
/M1: J1.38, U4.27
/MREQ: J1.32, U4.19
/NMI: J1.40, U4.17
/OCS: J1.47, ROM1.20
/OOE: J1.46, ROM1.22
/OWE: J1.45, ROM1.27
/RD: J1.34, U4.21
/RESET: J2.1, U4.26
/RFSH: J1.37, U4.28
/VCC5: C1.1, C2.1, C3.1, C4.1, C5.1, J2.5, RAM1.28, RAM2.28, ROM1.28, U4.11
/WAIT: J1.36, U4.24
/WR: J1.33, U4.22

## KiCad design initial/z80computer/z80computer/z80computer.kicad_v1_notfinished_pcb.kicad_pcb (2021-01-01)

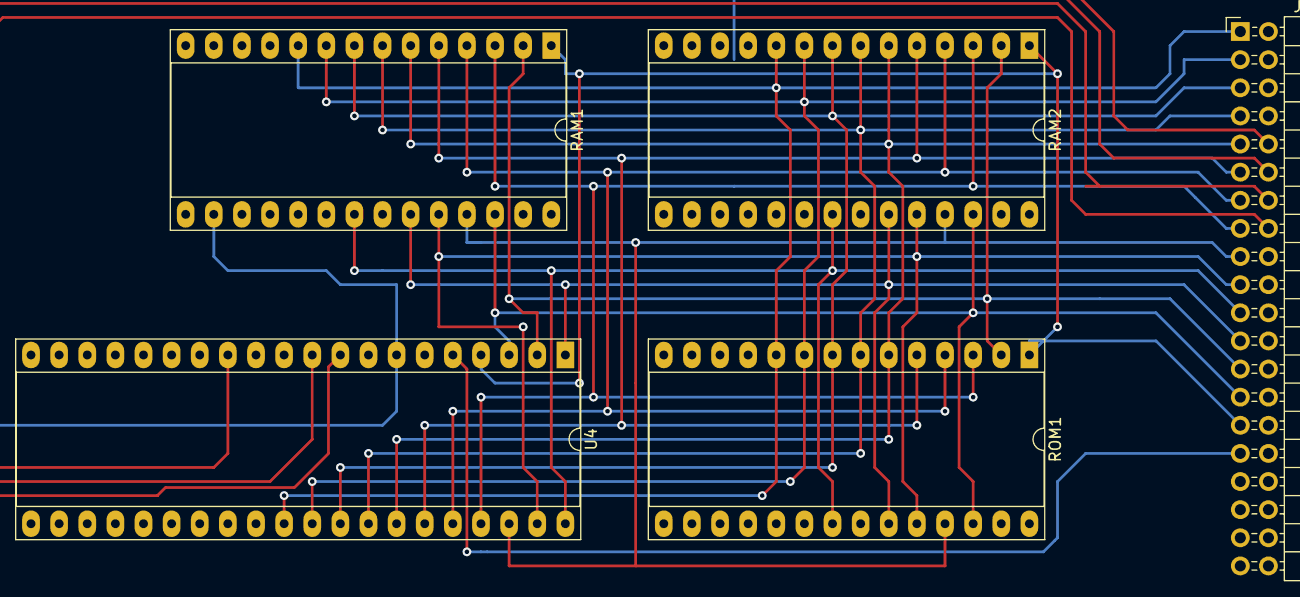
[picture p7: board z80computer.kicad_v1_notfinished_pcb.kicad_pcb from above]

Board: 2 copper layers, 5 parts (0 on the bottom side), 24 nets.

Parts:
J1: Conn_02x20_Top_Bottom; PinHeader_2x20_P2.54mm_Horizontal
RAM1, RAM2: AS6C62256; DIP-28_W15.24mm_Socket_LongPads
ROM1: AT28C64B; DIP-28_W15.24mm_Socket_LongPads
U4: Z80CPU; DIP-40_W15.24mm_Socket_LongPads

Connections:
/A0: J1.1, RAM1.10, RAM2.10, ROM1.10, U4.30
/A1: J1.3, RAM1.9, RAM2.9, ROM1.9, U4.31
/A2: J1.5, RAM1.8, RAM2.8, ROM1.8, U4.32
/A3: J1.7, RAM1.7, RAM2.7, ROM1.7, U4.33
/A4: J1.9, RAM1.6, RAM2.6, ROM1.6, U4.34
/A5: J1.11, RAM1.5, RAM2.5, ROM1.5, U4.35
/A6: J1.13, RAM1.4, RAM2.4, ROM1.4, U4.36
/A7: J1.15, RAM1.3, RAM2.3, ROM1.3, U4.37
/A8: J1.17, RAM1.25, RAM2.25, ROM1.25, U4.38
/A9: J1.19, RAM1.24, RAM2.24, ROM1.24, U4.39
/A10: J1.21, RAM1.21, RAM2.21, ROM1.21, U4.40
/A11: J1.23, RAM1.23, RAM2.23, ROM1.23, U4.1
/A12: J1.25, RAM1.2, RAM2.2, ROM1.2, U4.2
/A13: J1.27, RAM1.26, RAM2.26, ROM1.26, U4.3
/A14: J1.29, RAM1.1, RAM2.1, ROM1.1, U4.4
/A15: J1.31, U4.5
/D0: J1.2, RAM1.11, RAM2.11, ROM1.11, U4.14
/D1: J1.4, RAM1.12, RAM2.12, ROM1.12, U4.15
/D2: J1.6, RAM1.13, RAM2.13, ROM1.13, U4.12
/D3: J1.8, RAM1.15, RAM2.15, ROM1.15, U4.8
/D4: J1.10, RAM1.16, RAM2.16, ROM1.16, U4.7
/D5: J1.12, RAM1.17, RAM2.17, ROM1.17, U4.9
/D6: J1.14, RAM1.18, RAM2.18, ROM1.18, U4.10
/D7: J1.16, RAM1.19, RAM2.19, ROM1.19, U4.13

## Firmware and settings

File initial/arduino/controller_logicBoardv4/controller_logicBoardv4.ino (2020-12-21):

#define SERIAL_TX_BUFFER_SIZE 2
#define SERIALPORT 1
#define VERSION "\nSerialPort Ready v0.0.0,Device id 0x01"
// IO device port 0x01


uint8_t character = 0; // character to send
int characterpause = 0;
#define keypressdelay  100
int xcontrol = 1; // xon=char(19), xoff=char(17). xcontrol=1 = enabled


#define DELAY 10
// CLK,WAIT arduino pins used

#define RESETZ80 8
#define WAIT 13
#define RFSH 12
#define HASPOWER 11
#define IOREQ 42 // not used I hope
#define M1 4
#define IOREAD 2
#define INT 5
#define D0 22
#define D1 23
#define D2 24
#define D3 25
#define D4 26
#define D5 27
#define D6 28
#define D7 29
#define ACTIVE 40  // comes from GAL ATF16V8 (ACTIVE LOW)


#define DEBUG
#ifdef DEBUG
#define DWRITE(c) Serial.println(c)
#else
#define DWRITE(c)
#endif

void setup() {
  // put your setup code here, to run once:


  setMode(INPUT);
#ifdef DEBUG
  Serial.begin(115200);
  while (!Serial) ;
  DWRITE(VERSION);
#endif
  pinMode(HASPOWER, INPUT);
  pinMode(INT, OUTPUT); digitalWrite(INT, HIGH);
  pinMode(IOREQ, INPUT);
  pinMode(M1, INPUT);
  pinMode(IOREAD, INPUT);
  pinMode(ACTIVE, INPUT);
  pinMode(RFSH, INPUT);
  digitalWrite(WAIT, HIGH);

  DoRead(INPUT);


  DWRITE("Time setup complete");
  // reset the z80
  pinMode(RESETZ80, OUTPUT);
  digitalWrite(RESETZ80, LOW);
  for (int i = 0; i < 20; i++)
    delay(2);
  digitalWrite(RESETZ80, HIGH);
  pinMode(RESETZ80, INPUT);
  DWRITE("Reset complete");

}

void setMode(uint8_t mode)
{
  //pinMode(CLK, mode);
  pinMode(WAIT, mode);

}
/* change the direction of IO pins for reading or writing */
void DoRead(uint8_t mode)
{
  pinMode(D0, mode);
  pinMode(D1, mode);
  pinMode(D2, mode);
  pinMode(D3, mode);
  pinMode(D4, mode);
  pinMode(D5, mode);
  pinMode(D6, mode);
  pinMode(D7, mode);


}

/* write to the databus */
void write(uint8_t c)
{
  DoRead(OUTPUT);
  //DWRITE("busWrite"); DWRITE(c);
  for (int i = 0; i < 8; i++)
  {
    digitalWrite(D7 - i, (c >> 7));
    //DWRITE((c >> 7));
    c = c << 1;
  }
}

void readchannel( uint8_t *_c)
{
  // problem with compiler not setting variables. so needed to create
  // local variables here. argggg
  uint8_t c = 0;
  uint8_t d = 0;
  DoRead(INPUT);
  c = (c << 1) | digitalRead(D7);
  c = (c << 1) | digitalRead(D6);
  c = (c << 1) | digitalRead(D5);
  c = (c << 1) | digitalRead(D4);
  c = (c << 1) | digitalRead(D3);
  c = (c << 1) | digitalRead(D2);
  c = (c << 1) | digitalRead(D1);
  c = (c << 1) | digitalRead(D0);
  *_c = c;
}


uint8_t c = 0;
void handleioacknowledge()
{

  /*    Serial.print("ioreq="); Serial.print(ioreq);
      Serial.print(",Active="); Serial.print(digitalRead(ACTIVE));
      Serial.print(",M1="); Serial.println(m1);
  */
  digitalWrite(INT, HIGH);
 


  if (character != 0  ) { // this is for interrupt mode 1 or mode 2
    write(2); // vector for mode 2, note this code will also work with mode 1

    // test ioreq pin
    if (digitalRead(IOREQ) == HIGH) {
      Serial.print("ooops");
    }
    int ccc = 0;


    /*    digitalWrite(WAIT, LOW);
        // may need a pause
        // while (digitalRead(ACTIVE) == LOW); // wait for the low state to change
        while (digitalRead(IOREQ) == LOW) ccc++; // wait for the low state to change
        digitalWrite(WAIT, HIGH);
    */
    // this is working for the interrupts, the refresh happens after the z80 has accepted the data byte
    digitalWrite(WAIT, LOW);
    // may need a pause
    digitalWrite(WAIT, HIGH);
    while (digitalRead(RFSH) == LOW) ; // wait for the low state to change



    DoRead(INPUT);
    //Serial.println(ccc);

  } else {
    Serial.print("hey whats going on");
    write(2); // vector for mode 2, note this code will also work with mode 1


    digitalWrite(WAIT, LOW);
    // may need a pause
    while (digitalRead(IOREQ) == LOW); // wait for the low state to change
    DoRead(INPUT);
    digitalWrite(WAIT, HIGH);
    //  while (digitalRead(RFSH)==LOW); // extra 1 for testing
  }
  //digitalWrite(WAIT, HIGH);


}


void handleiorequest()
{
  // only process when active = low


  bool IsRead = digitalRead(IOREAD);
  if (!IsRead) {
    readchannel(&c);
    if (c == 19) xcontrol = 0; // xoff - disable sending keystrokes - allow processor time to process
    if (c == 17) xcontrol = 1; // xon - enable sending keystrokes again - keyboard
    if (c == 0)
    {
      Serial.println("zero");
    } else {
      Serial.print((char)c);
    }


    // may need a pause
    while (digitalRead(ACTIVE) == LOW)  {
      digitalWrite(WAIT, LOW);  // wait for the low state to change
//      Serial.print('P');
    }
    digitalWrite(WAIT, HIGH);



  } else {// !isread



    if (character == 0) character = '+';
    write(character);
    character = 0; 
    //Serial.print("X");


    /*   digitalWrite(WAIT, LOW);
       // may need a pause
      //while (digitalRead(ACTIVE) == LOW) ; // wait for the low state to change
      while (digitalRead(IOREQ) == LOW) ; // wait for the low state to change

      digitalWrite(WAIT, HIGH);
    */

//delay(1000);
    while (digitalRead(ACTIVE) == LOW) {
      digitalWrite(WAIT, LOW) ;  // wait for the low state to change
    //  Serial.print('*');
    }
    DoRead(INPUT);
    digitalWrite(WAIT, HIGH);

   



  }
}

void loop() {
  //digitalWrite(WAIT, LOW);
  int ioreq = digitalRead(IOREQ);

  int m1 = digitalRead(M1);

  if (ioreq == LOW && m1 == LOW) {
    handleioacknowledge();
  } else {

    int active = digitalRead(ACTIVE);
    if (active == LOW) {
      handleiorequest();

    } else {


      // if active low
    }

    // xon/xoff flow control
  } // intack
  //if (xcontrol == 1) {
  if (character == 0 && Serial.available()) {
    // discovered the z80 will just allow interrupts after interrupts therefore not allowing
    // the processor time to deal with the data. so we will not send keys without a pause between
    // each character.
    characterpause++;
    if (characterpause > keypressdelay)
    {
      characterpause = 0;
      character = Serial.read();
     // Serial.print("N");
      digitalWrite(INT, LOW); // hold it low until we get a response.
    


    }
  } 

  //}
  // change the current mode;
  setMode(digitalRead(HASPOWER));

} // void loop

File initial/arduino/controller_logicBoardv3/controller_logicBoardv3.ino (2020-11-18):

#define SERIALPORT 1
#define VERSION "\nSerialPort Ready v0.0.0a,Device id 0x01"
// IO device port 0x01

int capture = 0;
boolean captured = false;
int character = 0; // the character we want to send to the z80

int iostate = 0; // tracks the initiated interrupt we created
int cycledsinceio = 0;

#define DELAY 0
// CLK,WAIT arduino pins used

#define RESETZ80 8
#define CLK 12
#define WAIT 13
#define HASPOWER 11
#define IOREQ 3
#define M1 4
#define IOREAD 2
#define INT 5
#define D0 22
#define D1 23
#define D2 24
#define D3 25
#define D4 26
#define D5 27
#define D6 28
#define D7 29
#define I0 40
#define I1 41
#define I2 42
#define I3 43
#define I4 44
#define I5 45
#define I6 46
#define I7 47


#define DEBUG
#ifdef DEBUG
#define DWRITE(c) Serial.println(c)
#else
#define DWRITE(c)
#endif

void setup() {
  // put your setup code here, to run once:

  setMode(INPUT);
#ifdef DEBUG
  Serial.begin(9600);
  while (!Serial) ;
  DWRITE(VERSION);
#endif
  pinMode(HASPOWER, INPUT);
/*  if (digitalRead(HASPOWER)==0) 
  {
    Serial.print("Exit on power up");
    exit(0);
  }*/
  
  pinMode(INT, OUTPUT); digitalWrite(INT, HIGH);// DWRITE("INT HIGH");
  pinMode(IOREQ, INPUT);
  pinMode(M1, INPUT);
  pinMode(IOREAD, INPUT);

  DoRead(INPUT);
  pinMode(I0, INPUT);
  pinMode(I1, INPUT);
  pinMode(I2, INPUT);
  pinMode(I3, INPUT);
  pinMode(I4, INPUT);
  pinMode(I5, INPUT);
  pinMode(I6, INPUT);
  pinMode(I7, INPUT);

  



  // reset the z80
  pinMode(RESETZ80,OUTPUT);
  digitalWrite(RESETZ80,LOW);
  for (int i=0; i < 4;i++)
    clock(false);
  digitalWrite(RESETZ80,HIGH);
  pinMode(RESETZ80,INPUT);
}
void clock(bool half)
{
  digitalWrite(CLK, HIGH);
  delay(DELAY);
  digitalWrite(CLK, LOW);
  delay(DELAY);
}

/* when we create an interrupt request we can't process any keypress until
    the interrupt has been serviced. to ensure that happens we set the iostate
    flag. this flag it cleared after the io request has been acknowledged and
    the output has been written to the z80
*/
void createInterruptRequest()
{
  digitalWrite(INT, LOW);
  for (int b = 0 ; b < 4; b++) {
    clock(false);
  }
  digitalWrite(INT, HIGH);
  iostate = 1;
}
void setMode(uint8_t mode)
{
  pinMode(CLK, mode);
  pinMode(WAIT, mode);

}
/* change the direction of IO pins for reading or writing */
void DoRead(uint8_t mode)
{
  pinMode(D0, mode);
  pinMode(D1, mode);
  pinMode(D2, mode);
  pinMode(D3, mode);
  pinMode(D4, mode);
  pinMode(D5, mode);
  pinMode(D6, mode);
  pinMode(D7, mode);

  pinMode(I0, mode);
  pinMode(I1, mode);
  pinMode(I2, mode);
  pinMode(I3, mode);
  pinMode(I4, mode);
  pinMode(I5, mode);
  pinMode(I6, mode);
  pinMode(I7, mode);

}
/* write to the databus */
void write(uint8_t c)
{
  DoRead(OUTPUT);
  // DWRITE("busWrite"); DWRITE(c);
  for (int i = 0; i < 8; i++)
  {
    digitalWrite(D7 - i, (c >> 7));
    c = c << 1;
  }
}


void readchannel(uint8_t *_d, uint8_t *_c)
{
  // problem with compiler not setting variables. so needed to create
  // local variables here. argggg
  uint8_t c = 0;
  uint8_t d = 0;
  DoRead(INPUT);
  c = (c << 1) | digitalRead(D7);
  c = (c << 1) | digitalRead(D6);
  c = (c << 1) | digitalRead(D5);
  c = (c << 1) | digitalRead(D4);
  c = (c << 1) | digitalRead(D3);
  c = (c << 1) | digitalRead(D2);
  c = (c << 1) | digitalRead(D1);
  c = (c << 1) | digitalRead(D0);

  d = (d << 1) | digitalRead(I7);
  d = (d << 1) | digitalRead(I6);
  d = (d << 1) | digitalRead(I5);
  d = (d << 1) | digitalRead(I4);
  d = (d << 1) | digitalRead(I3);
  d = (d << 1) | digitalRead(I2);
  d = (d << 1) | digitalRead(I1);
  d = (d << 1) | digitalRead(I0);

  *_c = c;
  *_d = d;
  // DWRITE("Device:"); DWRITE(d);
}

void performIO(uint8_t c)
{
  bool IsRead = digitalRead(IOREAD);
  if (!IsRead) {
    // DWRITE("Read from Z80");
    capture = c;
    captured = true;
    // after the read perform 2 more clock cycles
    clock(false); clock(false);
    if (iostate == 3) {
      // this can only happen if we initiated the ioreq
      iostate = 4;
    }
    // }
  } else {
    /* before we write the data we should validate the IO address but we don't do that yet. oops*/
    if (iostate == 2) {
      // we can only write the data the iostate is 2 because that tells me
      // we initiated the ioreq
      //DWRITE("Write to Z80");
      write(character);
      // after the character has been sent we clear it out.
      character = 0;

      clock(false);
      DoRead(INPUT);
      iostate = 3;
    } // iostate 2
  }

}

void IORequest()
{
  int m1 = digitalRead(M1);
  int ioreq = digitalRead(IOREQ);

  bool InterruptACK =  (m1 == LOW && ioreq == LOW) ? HIGH : LOW;

  // if we do get an interrupt ack when we didnt ask for it than it's not ours and we should
  // ignore it. so we check the iostate to see it we should respond
  // *****
  if (InterruptACK && iostate == 1)
  {
    /*
      // read from z80 = low, write to z80 = high;
      this appears odd. the _WR pin from the Z80 is connected the arduino IOREAD. so if the _WR is low
      it means the z80 is trying to write into the arduino.
    */
    /* during an interrupt ack,
          reading a0-a7 will return address of the current PC
          reading d0-d7 will return the data at the address of PC
          so there's no point in reading these values.

        uint8_t d = 0;
          uint8_t c = 0;
          readchannel(&d, &c);
          DWRITE("****");
        DWRITE(d); DWRITE(c);

    */

    //DWRITE("interrupt ack ");
    uint8_t vector = 2; // mode 2 interrupt vector.
    write(vector);
    clock(false);
    // set it back to input or we will be writing data on who knows what.
    DoRead(INPUT);
    iostate = 2;

  } else {

    uint8_t d = 0;
    uint8_t c = 0;
    readchannel(&d, &c);

    if (d == SERIALPORT)
    {
      /* before we read the data we should validate the IO address*/
      performIO(c);
    } // if device == serialport
  } // end interrupt write

  return ;
}
void loop() {
  // clock signal
 /* if (digitalRead(HASPOWER)==0) 
  {
    Serial.print("Exit on power up");
    exit(0);
  }*/
  clock(false);

  if (digitalRead(IOREQ) == LOW)
  {
    IORequest();
  }
  if (captured)
  {
    captured = false;
    Serial.print((char)capture);
    iostate = 0;
  }
  if (iostate == 0)
  {
    // why not reset the count.
    if (cycledsinceio > 30000) cycledsinceio = 0;
  } else {
    cycledsinceio = 0;
  }
  cycledsinceio++;

  // read from terminal -
  // i don't understand why I need to wait for 26+ cycles before sending more data
  if (Serial.available() > 0 && cycledsinceio > 25 ) {
    if (character == 0) {
      character = Serial.read();
      createInterruptRequest();
    }
  }


  digitalWrite(WAIT, HIGH);



  // change the current mode;
  setMode(digitalRead(HASPOWER));


}

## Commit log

2020-11-15 current state: serial port to/from putty is working. reading the sd card and echoing the data to the serial port is working keypress interrupts are not currently working. no idea why.
2020-11-24 add refresh pin - because it was causing chipselects to happen during a refresh. it appeared to randomly write into the rom and corrupt it.
2020-11-24 changed board layout to use logic chip to select active device for IO port operations. this removed 8 pins from the requirements and added 1 new pin. code restructured to use interrupt mode 1
2020-11-24 changed board layout to use logic chip to select active device for IO port operations. this removed 8 pins from the requirements and added 1 new pin. code restructured to use interrupt mode 1 removed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
2020-11-24 code fixed to work in mode1 or mode 2. note: the sequence of instructions is vital. to use mode 2, the im 2 instruction must be executed but loading the I register. im 2 #; is vital that the sequece 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
    [controller_logicBoardv4.ino]
2020-11-25 I increased the clock pulse. I tested the circuit with a 1mhz clock. the computer fails to run correctly. I attribute this to the slow processing of the arduinos. i've ordered some pic18 uC's that ru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
    [controller_logicBoardv4.ino]
2020-11-26 command line prompt is now minimal but working. added a new command 'hello' which will print a hello world message. currently programs are stored on the SD card.
2020-11-30 sd card is initalized if the file open failed. this is required because each time the card is removed it wouldn't read it again until it was initialized. during an open is the best time to test for t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
    [sdcard_boot.ino]
2020-12-11 removed clock code from arduino controller_logicboardv4 fixed a startup frequency on pic clock
    [controller_logicBoardv4.ino, main.c]
2020-12-19 changed the wait logic, this ucontroller only resets the wait flag on the logic chip (SDCARD), removed the clock reminants
    [controller_logicBoardv4.ino]
2021-01-01 added processor design board
    [z80computer-B_Cu.gbr, z80computer-B_Mask.gbr, z80computer-B_Paste.gbr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]
2021-01-03 added kicad template for board designs. also has currentv version of the boards ( back plane and processor board)
    [backplane.kicad_pcb, backplane.sch, z80computer.kicad_pcb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]
2021-01-08 version 1 circuit boards
    [backplane-B_Cu.gbr, backplane-B_Mask.gbr, backplane-B_SilkS.gbr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]

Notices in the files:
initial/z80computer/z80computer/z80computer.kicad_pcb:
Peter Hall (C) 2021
